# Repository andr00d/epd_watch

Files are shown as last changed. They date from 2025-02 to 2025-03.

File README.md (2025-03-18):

# epd watch

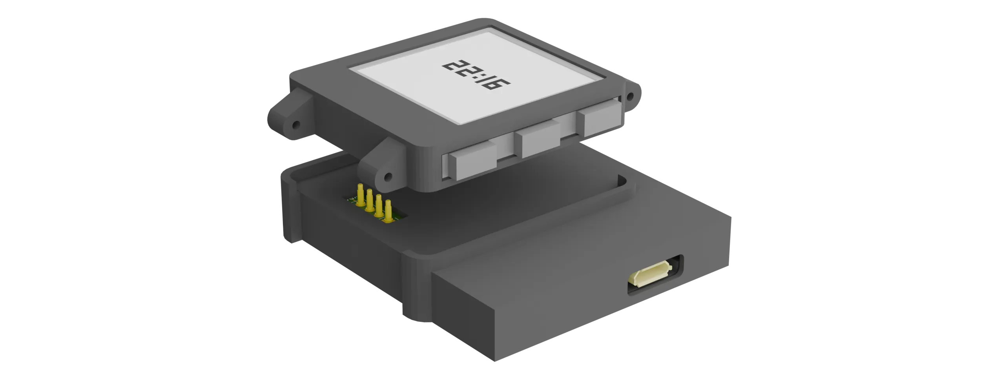
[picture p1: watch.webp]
epaper watch example
 

A low power epaper smartwatch running on an NRF52832.  
It has the basic functionalities like telling time, a stopwatch, and an alarm. But also has some fun features like snake.

## hardware
The kicad files for both the charger and the watch are in the hardware folder. The components in the watch already include LCSC values to order from JLCPCB, but its good to check and make sure every component is still available. Several components will also need to be rotated or moved a bit to ensure correct placement. 

Several extra components are also needed, for the display, the GDEW0154M09 is used. And 10x10x1mm magnets are used to keep the watch and charger connected. for the sound a simple flat piezo buzzer can be connected to one of the sound pins. the cutout in the PCB is the perfect size for a 202040/202030 battery if you want the biggest batttery possible.

The charger board is a simple pcb to easily connect 4 pogo pins to a pi pico which is flashed with [debugprobe](github.com/raspberrypi/debugprobe). Pogo pins of about 6mm should work best. 

in the 3D_models folder are all the stl files needed to print the cases for both the charger and the watch. the case for the watch should be able to be made watertight with some glue around the seams and the buttons covered, but this hasn't been tested yet. 

## running on the watch
A few steps are needed to be able to compile and run the code on the watch. running the following commands installs cargo embed and the correct target:  
```rustup target add thumbv7em-none-eabihf```  
```rustup component add llvm-tools```  
```cargo install cargo-binutils```  
```cargo install cargo-embed```

After this is finished, just place the watch on the charger and run ```cargo embed``` to flash the watch. 

## running on your pc
There is a pc_test folder that allows additions to the watch to be tested a bit more easily than having to constantly wait for the watch to be programmed. simply go into the pc_test folder, type ```cargo run``` and you can test if everything is as you expect.

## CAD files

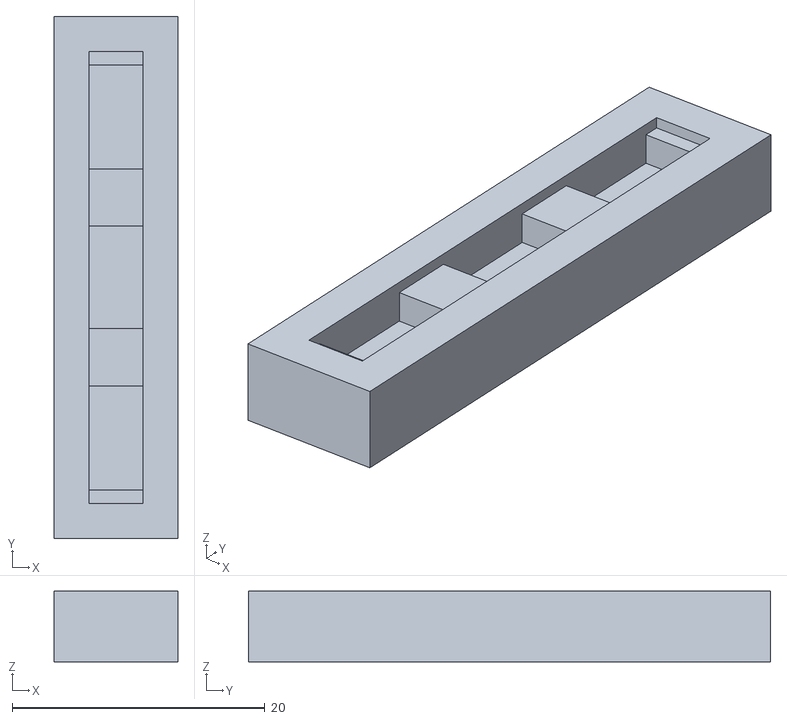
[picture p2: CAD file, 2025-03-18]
3D_models/button_mold.stl
9.80 x 41.3 x 5.59

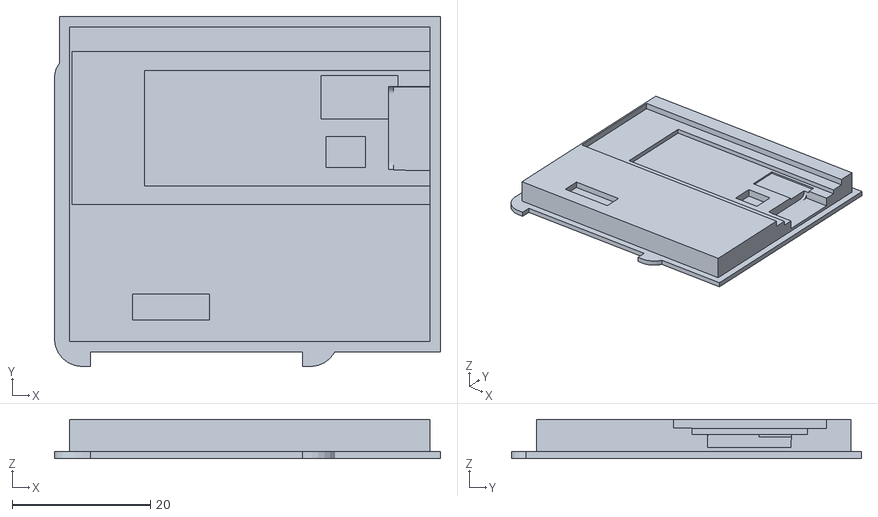
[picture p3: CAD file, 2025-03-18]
3D_models/charger_lid.stl
55.9 x 50.7 x 5.69

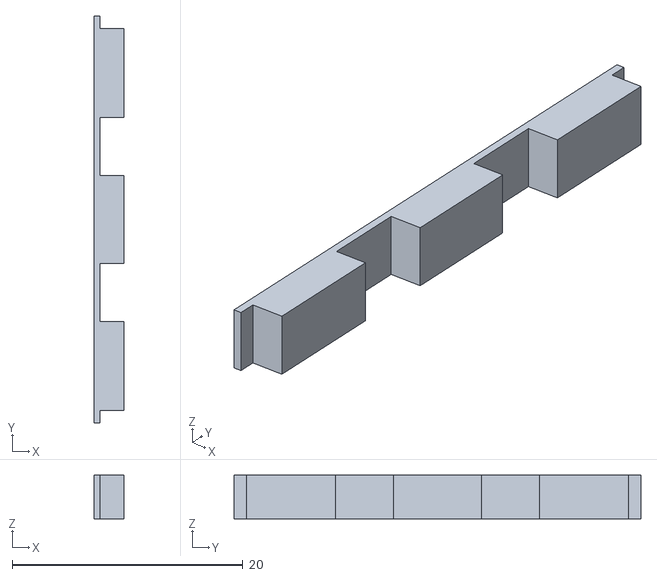
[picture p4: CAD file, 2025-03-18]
3D_models/watch_buttons.stl
2.59 x 35.3 x 3.80

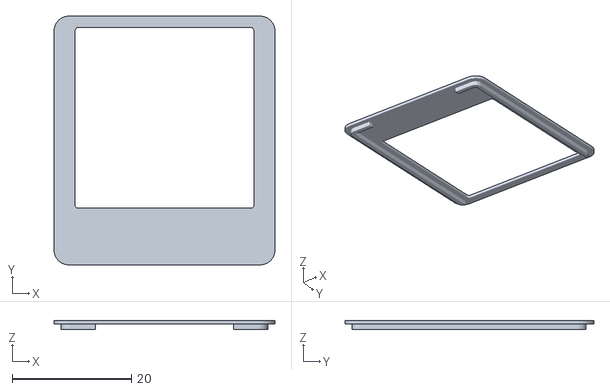
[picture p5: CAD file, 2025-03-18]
3D_models/watch_lid.stl
37.1 x 41.8 x 1.50

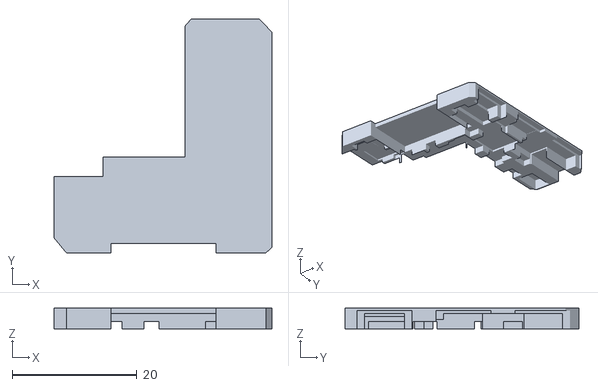
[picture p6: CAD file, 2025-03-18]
3D_models/watch_filler.stl
35.0 x 37.6 x 3.35

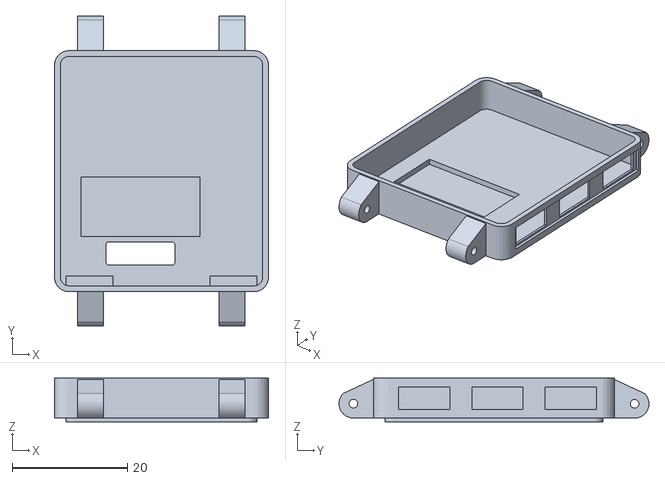
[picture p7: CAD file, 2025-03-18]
3D_models/watch_case.stl
37.1 x 53.7 x 7.59

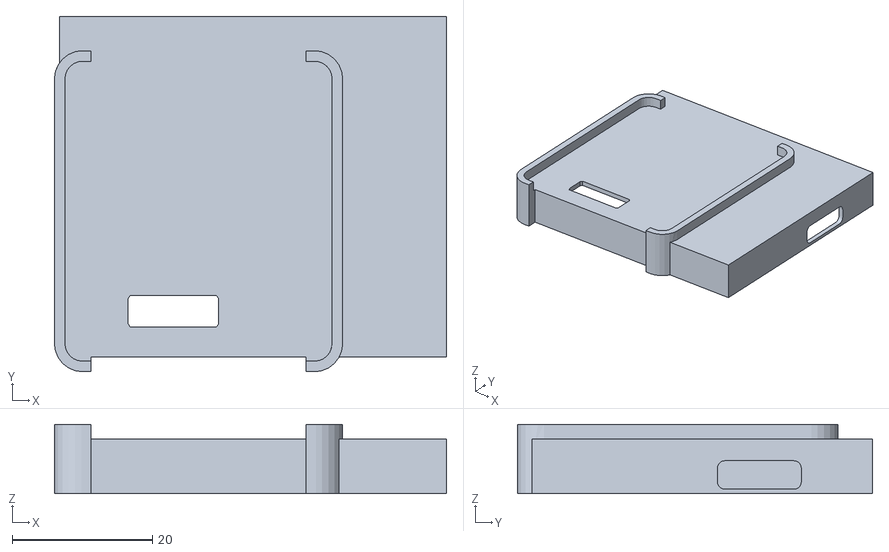
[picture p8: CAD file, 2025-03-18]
3D_models/charger_case.stl
55.9 x 50.7 x 9.88

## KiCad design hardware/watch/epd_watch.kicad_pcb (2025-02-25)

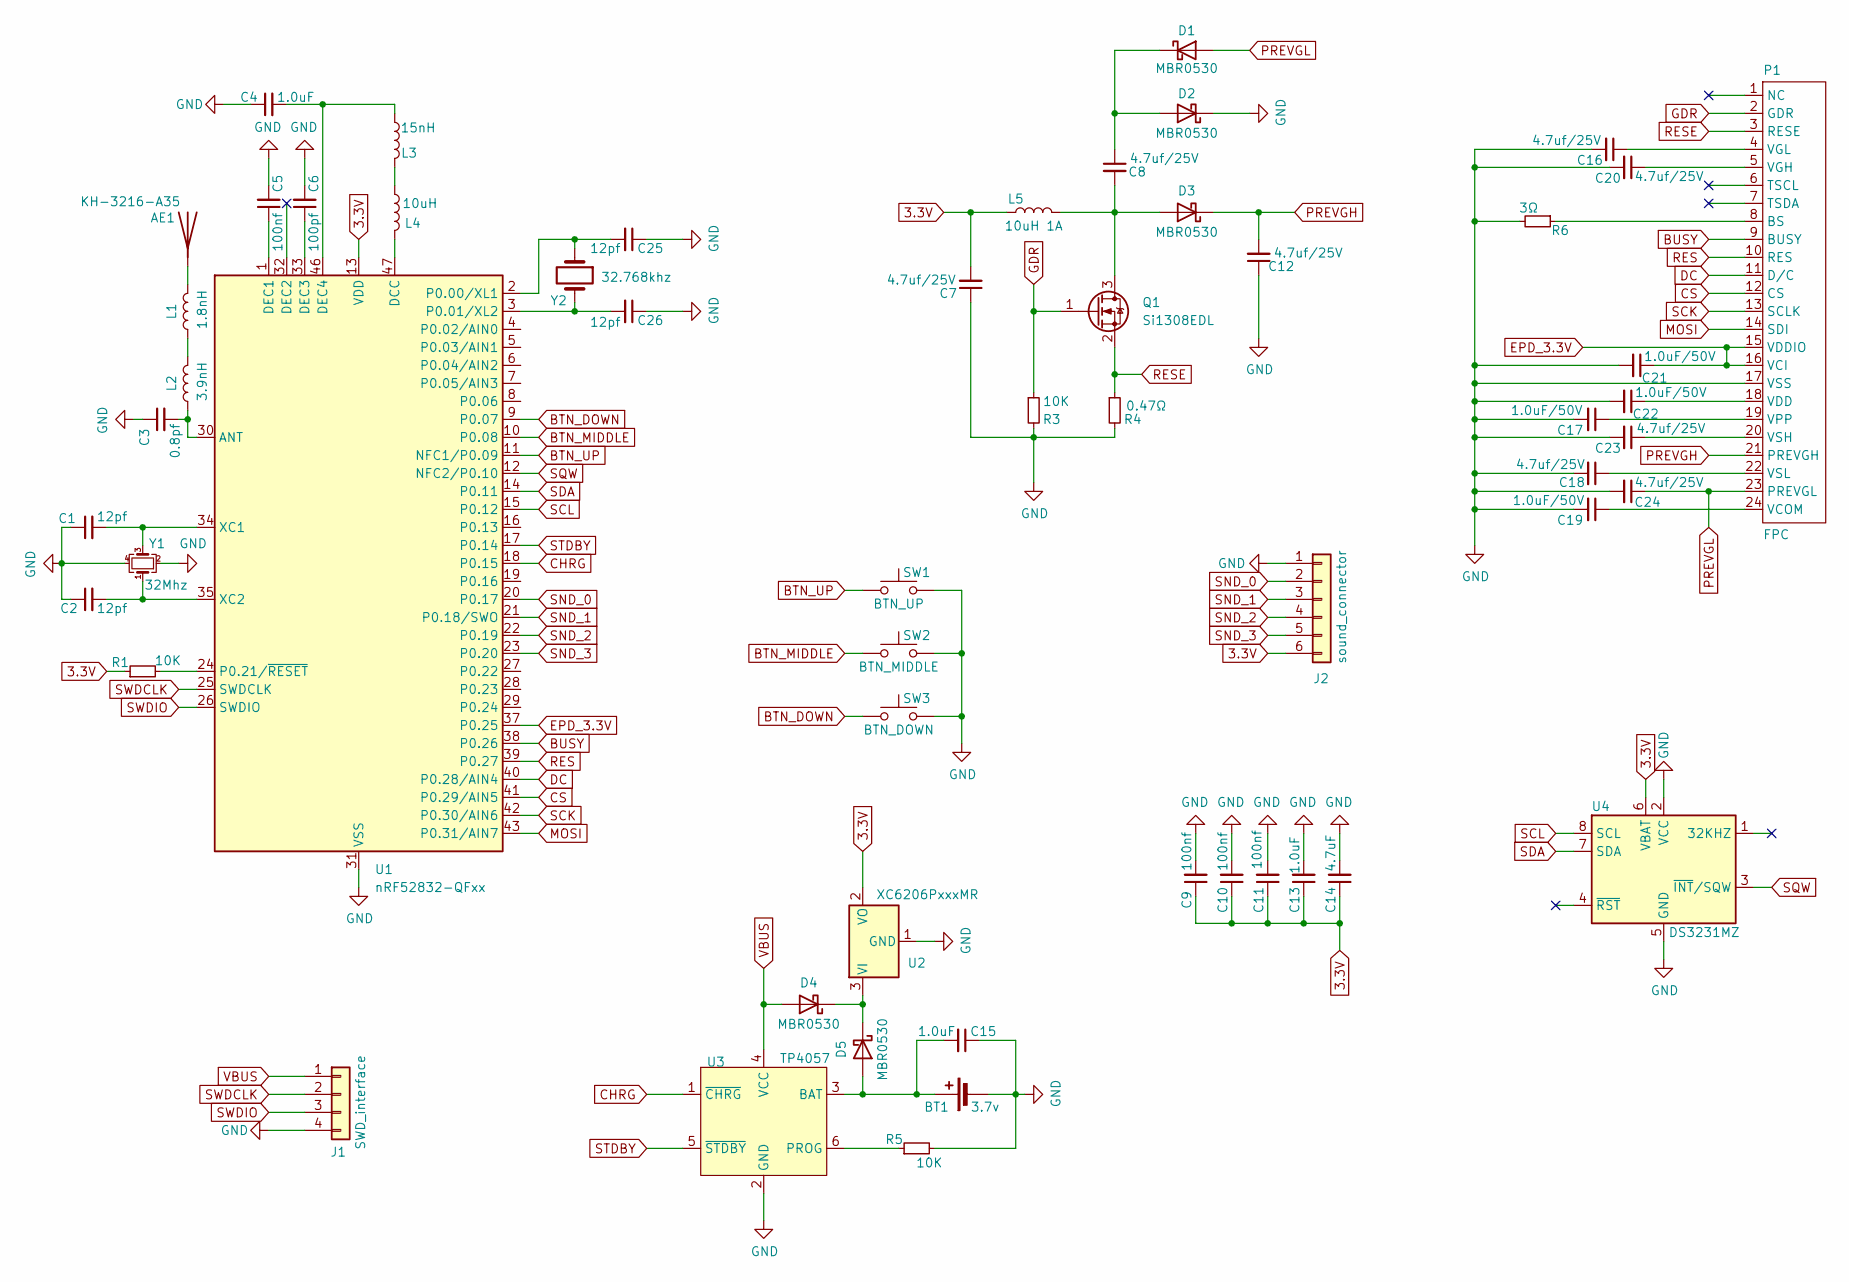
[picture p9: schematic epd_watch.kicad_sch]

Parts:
AE1: KH-3216-A35; LCSC C504002
BT1: 3.7v; batt_con
C1, C2, C25, C26: 12pf; C_0402_1005Metric; LCSC C161305
C3: 0.8pf; C_0402_1005Metric; LCSC C327032
C4, C13, C15: 1.0uF; C_0402_1005Metric; LCSC C7472948
C5, C9, C10, C11: 100nf; C_0402_1005Metric; LCSC C1525
C6: 100pf; C_0402_1005Metric; LCSC C1546
C7, C8, C12, C16, C18, C20, C23, C24: 4.7uf/25V; C_0402_1005Metric; LCSC C2858031
C14: 4.7uF; C_0402_1005Metric; LCSC C2858031
C17, C19, C21, C22: 1.0uF/50V; C_0402_1005Metric; LCSC C7472948
D1, D2, D3, D4, D5: MBR0530; D_SOD-123; LCSC C475718
J1: SWD_interface; pogo_conn
J2: sound_connector; PinSocket_1x06_P1.27mm_Vertical
L1: 1.8nH; L_0402_1005Metric; LCSC C703123
L2: 3.9nH; L_0402_1005Metric; LCSC C14033
L3: 15nH; L_0402_1005Metric; LCSC C329619
L4: 10uH; L_0805_2012Metric; LCSC C426327
L5: 10uH 1A; L_0805_2012Metric; LCSC C426327
P1: FPC; FPC-05F-24PH15; LCSC C2856821
Q1: Si1308EDL; SOT-323_SC-70; LCSC C469327
R1, R3, R5: 10K; R_0402_1005Metric; LCSC C25744
R4: 0.47Ω; R_0402_1005Metric; LCSC C423162
R6: 3Ω; R_0402_1005Metric; LCSC C423196
SW1: BTN_UP; TS-1010A-B; LCSC C381059
SW2: BTN_MIDDLE; TS-1010A-B; LCSC C381059
SW3: BTN_DOWN; TS-1010A-B; LCSC C381059
U1: nRF52832-QFxx; QFN-48-1EP_6x6mm_P0.4mm_EP4.6x4.6mm; LCSC C77540
U2: XC6206PxxxMR; SOT-23-3; LCSC C5446
U3: TP4057; SOT-23-6; LCSC C12044
U4: DS3231MZ; SOIC-8_3.9x4.9mm_P1.27mm; LCSC C107410
Y1: 32Mhz; Crystal_SMD_2016-4Pin_2.0x1.6mm; LCSC C2965582
Y2: 32.768khz; SMD3215; LCSC C32346

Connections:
3.3V: C7.2, C9.1, C10.1, C11.1, C13.1, C14.1, J2.6, L5.1, R1.1, U1.13 (VDD), U1.36 (VDD), U1.48 (VDD), U2.2 (VO), U4.6 (VBAT)
BTN_DOWN: SW3.1, U1.9 (P0.07)
BTN_MIDDLE: SW2.1, U1.10 (P0.08)
BTN_UP: SW1.1, U1.11 (NFC1/P0.09)
BUSY: P1.9 (BUSY), U1.38 (P0.26)
CHRG: U1.18 (P0.15), U3.1 (~CHRG)
CS: P1.12 (CS), U1.41 (P0.29/AIN5)
DC: P1.11 (D/C), U1.40 (P0.28/AIN4)
EPD_3.3V: C21.1, P1.15 (VDDIO), P1.16 (VCI), U1.37 (P0.25)
GDR: P1.2 (GDR), Q1.1 (G), R3.1
GND: BT1.2 (-), C1.1, C2.1, C3.1, C4.1, C5.2, C6.2, C7.1, C9.2, C10.2, C11.2, C12.1, C13.2, C14.2, C15.1, C16.2, C17.2, C18.2, C19.2, C20.2, C21.2, C22.2, C23.2, C24.2, C25.1, C26.1, D2.1 (K), J1.4, J2.1, P1.17 (VSS), R3.2, R4.2, R5.2, R6.2, SW1.2, SW2.2, SW3.2, U1.31 (VSS), U1.45 (VSS), U1.49 (VSS), U2.1 (GND), U3.2 (GND), U4.2 (VCC), U4.5 (GND), Y1.2, Y1.4
MOSI: P1.14 (SDI), U1.43 (P0.31/AIN7)
unnamed: AE1.1 (A), L1.2
unnamed: BT1.1 (+), C15.2, D5.2 (A), U3.3 (BAT)
unnamed: C8.1, D1.1 (K), D2.2 (A)
unnamed: C8.2, D3.2 (A), L5.2, Q1.3 (D)
unnamed: D4.1 (K), D5.1 (K), U2.3 (VI)
unnamed: L1.1, L2.2
unnamed: L3.2, L4.1
unnamed: P1.8 (BS), R6.1
unnamed: C19.1, P1.24 (VCOM)
unnamed: C22.1, P1.18 (VDD)
unnamed: C20.1, P1.5 (VGH)
unnamed: C16.1, P1.4 (VGL)
unnamed: C17.1, P1.19 (VPP)
unnamed: C23.1, P1.20 (VSH)
unnamed: C18.1, P1.22 (VSL)
unnamed: C3.2, L2.1, U1.30 (ANT)
unnamed: L4.2, U1.47 (DCC)
unnamed: C5.1, U1.1 (DEC1)
unnamed: C6.1, U1.33 (DEC3)
unnamed: C4.2, L3.1, U1.46 (DEC4)
unnamed: C25.2, U1.2 (P0.00/XL1), Y2.1
unnamed: C26.2, U1.3 (P0.01/XL2), Y2.2
unnamed: R1.2, U1.24 (P0.21/~RESET)
unnamed: C1.2, U1.34 (XC1), Y1.3
unnamed: C2.2, U1.35 (XC2), Y1.1
unnamed: R5.1, U3.6 (PROG)
PREVGH: C12.2, D3.1 (K), P1.21 (PREVGH)
PREVGL: C24.1, D1.2 (A), P1.23 (PREVGL)
RES: P1.10 (RES), U1.39 (P0.27)
RESE: P1.3 (RESE), Q1.2 (S), R4.1
SCK: P1.13 (SCLK), U1.42 (P0.30/AIN6)
SCL: U1.15 (P0.12), U4.8 (SCL)
SDA: U1.14 (P0.11), U4.7 (SDA)
SND_0: J2.2, U1.20 (P0.17)
SND_1: J2.3, U1.21 (P0.18/SWO)
SND_2: J2.4, U1.22 (P0.19)
SND_3: J2.5, U1.23 (P0.20)
SQW: U1.12 (NFC2/P0.10), U4.3 (~INT/SQW)
STDBY: U1.17 (P0.14), U3.5 (~STDBY)
SWDCLK: J1.2, U1.25 (SWDCLK)
SWDIO: J1.3, U1.26 (SWDIO)
VBUS: D4.2 (A), J1.1, U3.4 (VCC)

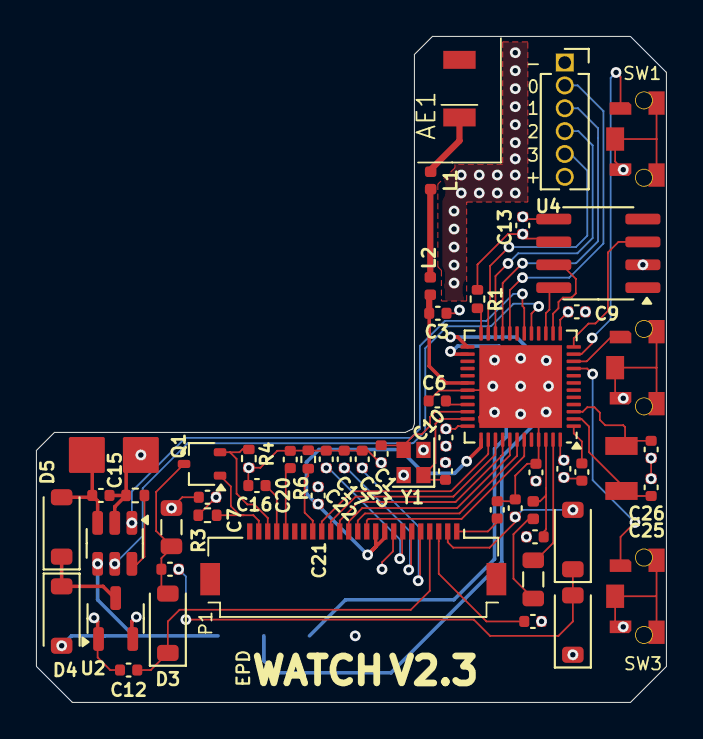
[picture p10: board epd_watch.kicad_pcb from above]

Board: 4 copper layers, 35.0 x 37.0 mm, 56 parts (1 on the bottom side), 54 nets.

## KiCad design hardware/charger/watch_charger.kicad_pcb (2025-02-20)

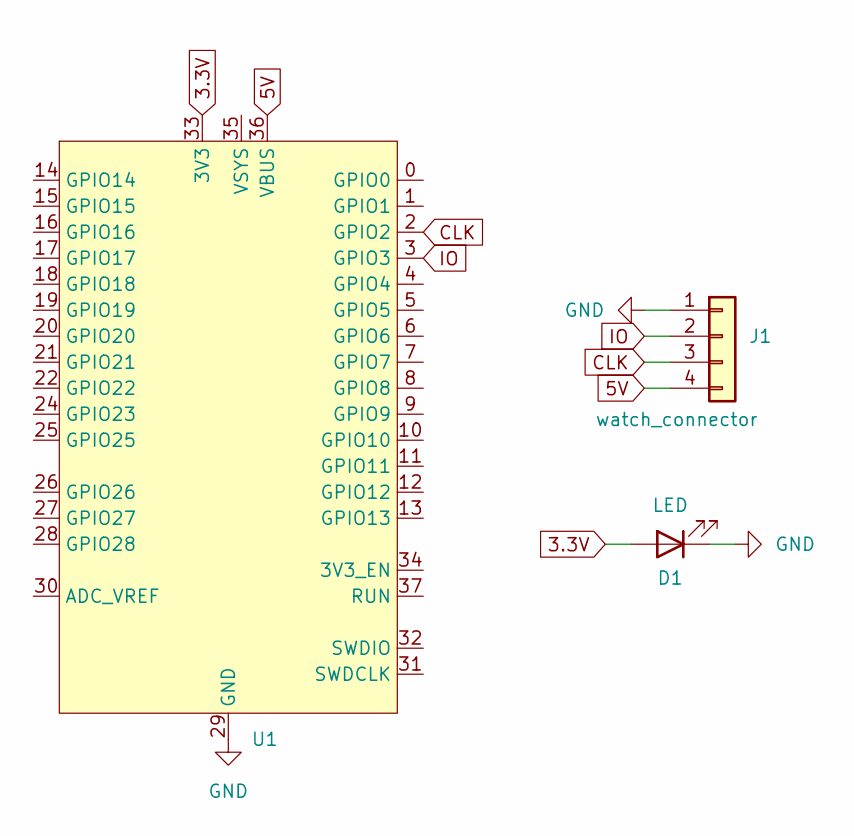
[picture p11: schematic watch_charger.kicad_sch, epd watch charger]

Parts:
D1: LED; PinSocket_1x02_P2.54mm_Vertical
J1: watch_connector; PinHeader_1x04_P2.54mm_Vertical
U1: pico

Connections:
3.3V: D1.2 (A), U1.33 (3V3)
5V: J1.4, U1.36 (VBUS)
CLK: J1.3, U1.2 (GPIO2)
GND: D1.1 (K), J1.1, U1.29 (GND)
IO: J1.2, U1.3 (GPIO3)

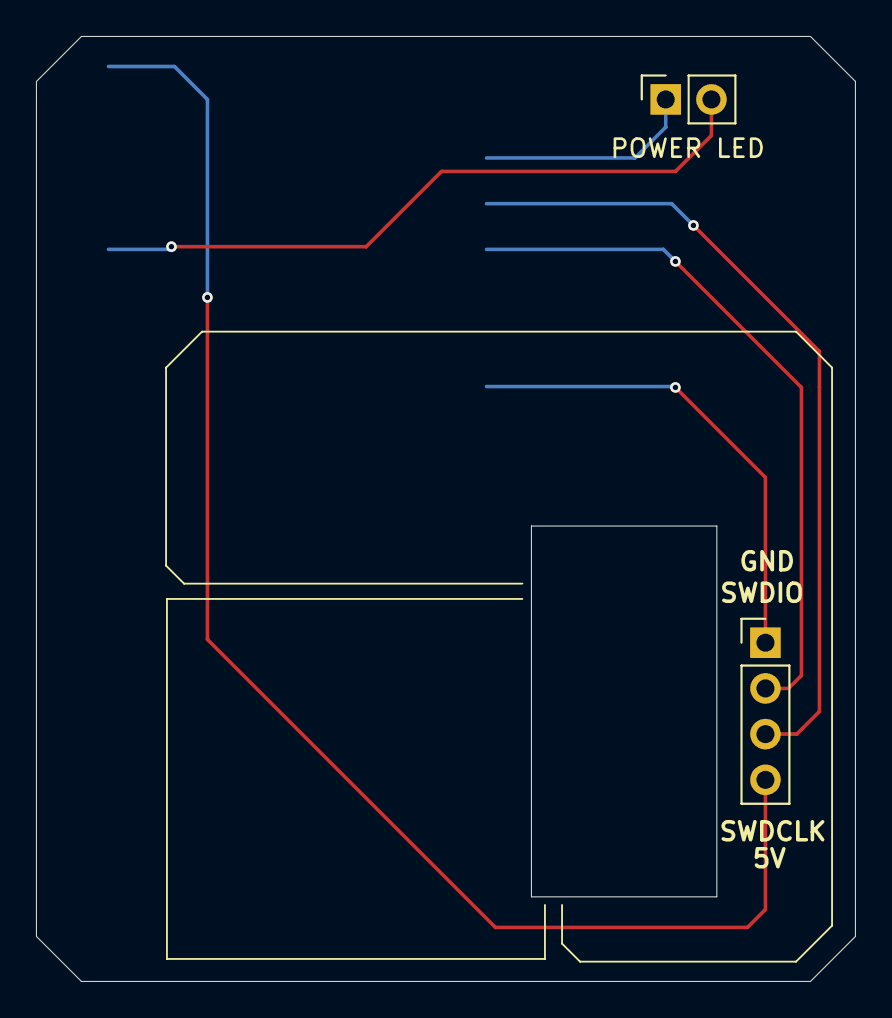
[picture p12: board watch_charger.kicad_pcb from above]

Board: 2 copper layers, 45.5 x 52.5 mm, 3 parts (1 on the bottom side), 5 nets.

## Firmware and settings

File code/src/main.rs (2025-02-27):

#![no_main]
#![no_std]

use cortex_m_rt::entry;
use hal::{pac, Rtc};
use nrf52832_hal::rtc::RtcInterrupt;
use nrf52832_hal as hal;
use rtt_target::{rtt_init_print, rprintln};
use nrf52832_hal::gpiote::Gpiote;

use crate::display::DispPins;
use crate::io::{Io, IoPins, Event};
use crate::shared_data::SharedData;
use crate::display::Display;
use crate::pages::Pages;


mod shared_data;
mod display;
mod io;
mod pages;

pub const NFCPINS: *mut u32 = 0x1000120C as *mut u32;

fn connect_parts() -> (Display, Io)
{
    let mut cp = hal::pac::CorePeripherals::take().unwrap();
    let p = pac::Peripherals::take().unwrap();
    let p0 = hal::gpio::p0::Parts::new(p.P0);
    let gpiote = Gpiote::new(p.GPIOTE);

    // i have to add this because im stupid and used NFC pins.
    unsafe
    {
        let curr_val = NFCPINS.read_volatile();
        if curr_val & 1 as u32 != 0x0
        {
            p.NVMC.config.write(|w| w.wen().wen());
            NFCPINS.write_volatile(0 as u32 | !(1 as u32));
            p.NVMC.config.write(|w| w.wen().ren());
            rprintln!("set NFC pins to GPIO");
        }
        else {rprintln!("NFC pins already set to GPIO");}
    }

    // enable dc/dc for lower power consumption
    p.POWER.dcdcen.write(|w| w.dcdcen().enabled());
    rprintln!("enabled DC/DC");
    
    let clocks = hal::clocks::Clocks::new(p.CLOCK);
    let _ = clocks.start_lfclk();
    let mut rtc = Rtc::new(p.RTC0, 0).unwrap();
    rtc.enable_interrupt(RtcInterrupt::Compare0, Some(&mut cp.NVIC));

    let disp_pins = DispPins 
    {
        power: p0.p0_25.degrade(),
        clk: p0.p0_30.degrade(),
        miso:  p0.p0_24.degrade(),
        mosi: p0.p0_31.degrade(),
        busy: p0.p0_26.degrade(),
        res: p0.p0_27.degrade(),
        cs: p0.p0_29.degrade(),
        dc: p0.p0_28.degrade(),
    };

    let io_pins = IoPins
    {
        scl: p0.p0_12.into_floating_input().degrade(),
        sda: p0.p0_11.into_floating_input().degrade(),
        alarm : p0.p0_10.into_pullup_input().degrade(),
        btn_up : p0.p0_09.into_pullup_input().degrade(),
        btn_mid : p0.p0_08.into_pullup_input().degrade(),
        btn_dwn : p0.p0_07.into_pullup_input().degrade(),
    };
    
    gpiote.port().input_pin(&io_pins.alarm).low();
    gpiote.port().input_pin(&io_pins.btn_up).low();
    gpiote.port().input_pin(&io_pins.btn_mid).low();
    gpiote.port().input_pin(&io_pins.btn_dwn).low();
    gpiote.port().enable_interrupt();

    let display = Display::new(p.SPIM2, disp_pins);
    let io = Io::new(p.TWIM0, rtc, gpiote, io_pins);
    return (display, io);
}

#[entry]
fn main() -> ! 
{
    rtt_init_print!();

    let (mut display, mut io) = connect_parts();
    let mut shared = SharedData::new(&mut display, &mut io);
    let mut pages = Pages::new();

    pages.update_page(Event::Minute, &mut shared);
    shared.display.update(&mut shared.io);
    rprintln!("startup done");

    loop 
    {
        if !shared.io.buffer_has_ev() {shared.display.sleep(&mut shared.io);}
        let ev = shared.io.wait_for_input(); 

        pages.update_page(ev, &mut shared);
        if shared.update {shared.display.update(&mut shared.io)};
    }
}

use core::panic::PanicInfo;
#[inline(never)]
#[panic_handler]
fn panic(info: &PanicInfo) -> ! {
    cortex_m::interrupt::disable();
    rprintln!("err!: {}", info);
    loop {}
}

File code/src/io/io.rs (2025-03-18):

use nrf52832_hal as hal;
use nrf52832_pac::interrupt;
use hal::gpiote::Gpiote;
use nrf52832_pac::RTC0;
use nrf52832_hal::rtc::{Rtc, RtcCompareReg, RtcInterrupt};
use embedded_hal::digital::InputPin;
use cortex_m::peripheral::NVIC;
use cortex_m::interrupt::{Mutex, free};

use chrono::{NaiveDateTime, NaiveDate, NaiveTime, TimeDelta};
use ds323x::{DateTimeAccess, Ds323x, Datelike, Timelike};
use ds323x::{DayAlarm2, WeekdayAlarm1, Hours, Alarm1Matching, Alarm2Matching};
use ds323x::interface::I2cInterface;
use ds323x::ic::DS3231;

use rtt_target::rprintln;
use circular_buffer::CircularBuffer;
use heapless::String;
use core::cell::RefCell;
use core::fmt::Write;
use core::ops::DerefMut;

use crate::io::{Io, IoPins, IntData, Event};

static INTDATA: Mutex<RefCell<Option<IntData>>> = Mutex::new(RefCell::new(None));
const MONTHS: [&str; 12] = ["jan", "feb", "mar", "apr" , "may", "jun", "jul", "aug", "sep", "oct", "nov", "dec"];
const DAYS: [&str; 7]    = ["mon", "tue", "wed", "thu", "fri", "sat", "sun"];
const DELAY_MS: u32 = hal::clocks::LFCLK_FREQ/1000 as u32; 

macro_rules! get_intdata {($cs:tt) => (INTDATA.borrow($cs).borrow_mut().deref_mut())}

#[interrupt]
fn GPIOTE() 
{
    free(|cs| {
        if let Some(ref mut int_data) = get_intdata!(cs) 
        {
            if int_data.alarm.is_low().unwrap() {int_data.buffer.push_back(check_rtc(&mut int_data.rtc));}
            if int_data.btn_up.is_low().unwrap() {int_data.buffer.push_back(Event::BtnUp);}
            if int_data.btn_mid.is_low().unwrap() {int_data.buffer.push_back(Event::BtnMid);}
            if int_data.btn_dwn.is_low().unwrap() {int_data.buffer.push_back(Event::BtnDown);}

            // quick & dirty debounce
            // TODO: make this not suck ass
            cortex_m::asm::delay(100_000);
            rprintln!("ev");
            int_data.gpiote.reset_events();
        }
    });
}

#[interrupt]
fn RTC0() 
{
    free(|cs| {
        if let Some(ref mut int_data) = get_intdata!(cs) 
        {
            int_data.rtc0.disable_counter();
            int_data.rtc0.clear_counter();
            int_data.rtc0.reset_event(RtcInterrupt::Compare0);
            int_data.timer_expired = true;
        }
    });   
}

fn check_rtc(rtc: &mut Ds323x<I2cInterface<hal::Twim<nrf52832_hal::pac::TWIM0>>, DS3231>) -> Event
{
    match rtc.has_alarm1_matched()
    {
        Ok(x) =>
        {
            if x
            {
                let _ = rtc.clear_alarm1_matched_flag();
                return Event::Alarm;
            }
        }
        Err(x) => {rprintln!("Error communicating with rtc: {:?}", x);}
    }

    match rtc.has_alarm2_matched()
    {
        Ok(x) =>
        {
            if x
            {
                let _ = rtc.clear_alarm2_matched_flag();
                return Event::Minute;
            }
        }
        Err(x) => {rprintln!("Error communicating with rtc: {:?}", x);}
    }

    return Event::NoEvent;
}

////////////////////////////////////////////

impl Io
{
    pub fn new(twi: hal::pac::TWIM0, rtc0: Rtc<RTC0>, gpiote: Gpiote, pins: IoPins) -> Io
    {
        let buffer = CircularBuffer::<5, Event>::new();
        let mut twim = hal::Twim::new(
            twi,
            hal::twim::Pins {sda: pins.sda, scl: pins.scl},
            hal::twim::Frequency::K100,
        );
        twim.enable();
    
        let mut rtc = Ds323x::new_ds3231(twim);

        let alarm = DayAlarm2{day: 1, hour: Hours::H24(1), minute: 1};
        rtc.set_alarm2_day(alarm, Alarm2Matching::OncePerMinute).unwrap();
        rtc.use_int_sqw_output_as_interrupt().unwrap();
        let _ = rtc.clear_alarm1_matched_flag();
        let _ = rtc.clear_alarm2_matched_flag();
        rtc.enable_alarm2_interrupts().unwrap();

        let data = IntData
        {
            rtc: rtc,
            gpiote: gpiote,
            rtc0: rtc0,
            timer_expired: false,
            buffer: buffer,
            alarm: pins.alarm,
            btn_up: pins.btn_up,
            btn_mid: pins.btn_mid,
            btn_dwn: pins.btn_dwn, 
        };

        
        cortex_m::interrupt::free(|cs| {
            INTDATA.borrow(cs).replace(Some(data));
        });

        NVIC::unpend(interrupt::GPIOTE);
        NVIC::unpend(interrupt::RTC0);
        unsafe { NVIC::unmask(interrupt::GPIOTE) };

        return Io {};
    }

    ////////////////////////////////////////////

    pub fn wait_for_input(&mut self) -> Event
    {
        let mut ev = None;
        while ev == None
        {
            cortex_m::interrupt::free(|cs| {
                if let Some(ref mut int_data) = get_intdata!(cs) 
                {
                    ev = int_data.buffer.pop_front();
                }
            });
            
            if ev.is_some() {return ev.unwrap();}
            rprintln!("wfi");
            cortex_m::asm::wfi();
            
            cortex_m::interrupt::free(|cs| {
                if let Some(ref mut int_data) = get_intdata!(cs) 
                {
                    ev = int_data.buffer.pop_front();
                }
            });
        }

        return ev.unwrap();
    }    

    fn wait_ms_ev(&mut self, delay_ms: u32, ev_break: bool) -> Event
    {
        let mut expired = false;
        let mut ev = None; 

        cortex_m::interrupt::free(|cs| {
            if let Some(ref mut int_data) = get_intdata!(cs) 
            {
                int_data.rtc0.set_compare(RtcCompareReg::Compare0, DELAY_MS*delay_ms).unwrap();
                int_data.rtc0.enable_counter();
            }
        });

        loop
        {
            cortex_m::asm::wfi();

            cortex_m::interrupt::free(|cs| {
                if let Some(ref mut int_data) = get_intdata!(cs) 
                {
                    if (ev_break && int_data.buffer.front().is_some()) || int_data.timer_expired
                    {
                        if !int_data.timer_expired
                        {
                            int_data.rtc0.disable_counter();
                            int_data.rtc0.clear_counter();
                            int_data.rtc0.reset_event(RtcInterrupt::Compare0);
                        }
                        if ev_break {ev = int_data.buffer.pop_front();}

                        int_data.timer_expired = false;
                        expired = true;
                    }
                }
            });

            if ev.is_some() || expired {break;}
        }

        return ev.unwrap_or(Event::NoEvent);
    }

    pub fn get_input_waitms(&mut self, delay_ms: u32) -> Event
    {
        return self.wait_ms_ev(delay_ms, true);
        
    }

    pub fn waitms(&mut self, delay_ms: u32)
    {
        _ = self.wait_ms_ev(delay_ms, false);
    }

    pub fn buffer_has_ev(&self) -> bool
    {
        let mut has_ev = false;
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

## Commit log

2024-10-13 get interrupts working
2024-12-24 switched to nrf52832, fixed pc test
    [display.rs, io.rs, main.rs]
2025-02-20 added hardware files
    [epd_watch.kicad_pcb, epd_watch.kicad_sch, watch_charger.kicad_pcb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]
2025-02-25 didnt read datasheet well enough
    [epd_watch.kicad_pcb, epd_watch.kicad_sch]
2025-02-25 fixed bugs and power draw
    [display.rs, io.rs, main.rs]
2025-03-18 added case stls
    [button_mold.stl, charger_case.stl, charger_lid.stl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]
2025-04-18 first start at fixing battery measurement and lowering power consumption
    [charger_case.stl, charger_lid.stl, epd_watch.kicad_pcb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]
2025-04-24 finalized V2.4
    [epd_watch.kicad_pcb, epd_watch.kicad_sch]
2025-05-10 updated code to work for board
    [epd_watch.kicad_pcb]
2026-04-07 add quick part to make lining up charger easier
2026-10-19 fix battery protection whoopsie
